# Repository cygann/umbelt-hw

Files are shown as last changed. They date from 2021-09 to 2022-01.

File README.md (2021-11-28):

# umbelt-hw

This repo contains the hardware files for Umbelt: a sensory substitution belt
for everyday use. Designed to be worn around the waist underneath any belt,
Umbelt doesn't compromise on function or style. The name Umbelt (pronounced
"oom-belt") is a pun on the German word umwelt, used in English to describe an
organism's sensory environment and perceptions.

Sensory substitution "is a change of the characteristics of one sensory modality
into stimuli of another sensory modality."
([Wikipedia](https://en.wikipedia.org/wiki/Sensory_substitution))
This means that sensory modalities which are not otherwise accessible to an
individual can be recreated using haptic feedback on the waist. This includes
ordinary sensory functions for prosthetic purposes as well as sensory
information that is beyond typical human senses, such as electromagnetic
radiation outside the visible spectrum, the Earth's magnetic field, time,
physical proximity, velocity, or any other information in the computing world.

The initial configuration to try is the compass feature. This maps one's
absolute orientation to the waist by always indicating where north is whenever
the wearer's orientation changes. After wearing this for a while, the wearer
experiences subtle changes in spatial perception. It becomes more natural to
think in terms of absolute orientation, and separate locations become better
integrated into a larger, more continuous sense of space.

assembled Umbelt image

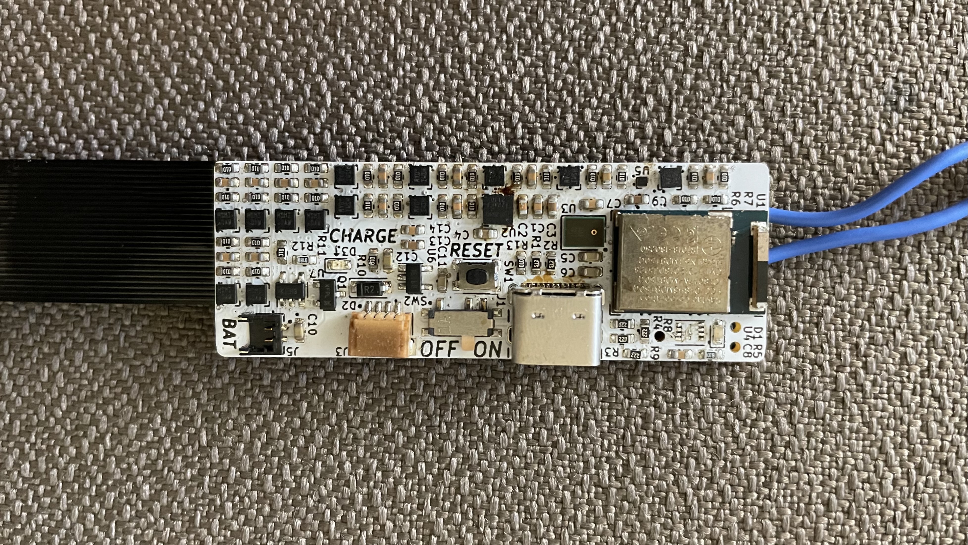
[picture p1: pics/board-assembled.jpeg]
assembled board image


# Hardware Design

Umbelt is designed as an assembly of two printed circuits: a rigid printed
circuit board (PCB) and a flexible printed circuit (FPC). The board mounts all
of the electronic components: the microcontroller, power regulators, 13 motor
drivers, integrated sensors (magnetometer, accelerometer/gyroscope, and
microphone), and connectors. The flex PC connects to the board and wraps around
the wearer's waist, providing electrical connections to 12 of the 13 motors.

The Microcontroller is a Raytac MDBT50Q-1MV2 module based on the Nordic nRF52840
bluetooth microcontroller. This bluetooth connection enables phone-based
configuration of Umbelt. A Sparkfun/Adafruit-style Qwiic expansion connector
allows for the daisy-chaining of additional I2C sensors to Umbelt.

Schematics and layout were designed with KiCad version 5.1.10.

Schematics can be found [here](umbelt-board/umbelt-board.pdf).

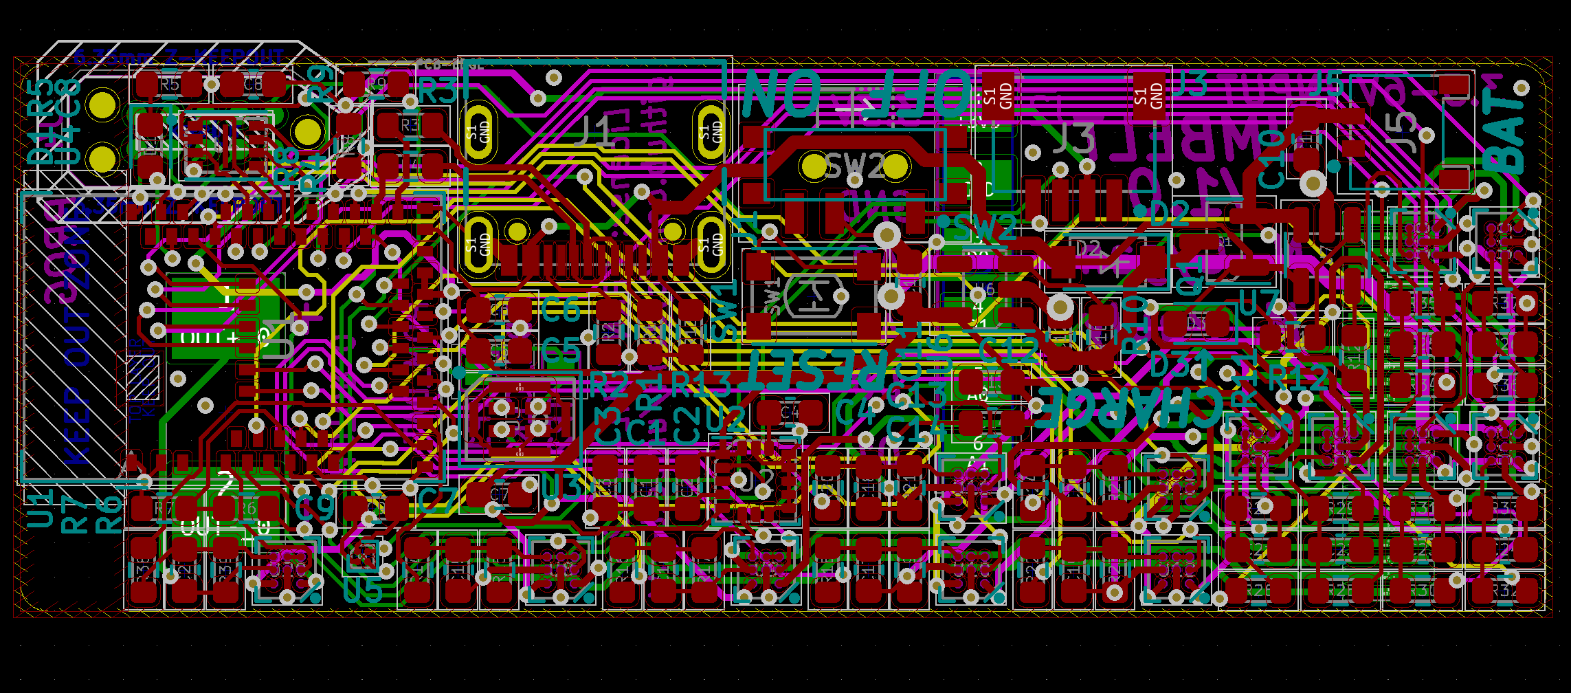
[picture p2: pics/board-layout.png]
board layout image


# Related Repositories

[Software](https://github.com/cygann/umbelt-sw). Haptic effects, sensor
libraries, and user programs.

[Bootloader](https://github.com/cygann/Adafruit_nRF52_Bootloader). This
is a modified version of the Adafruit Feather nRF52840 Sense bootloader, and
that target is to be used when compiling and flashing.

# License

_Creators' note: The aim of this license is to be semi-permissive: Umbelt may
be used in larger projects under different licenses but Umbelt itself and
modifications to it must be open-source under the same license. Refer to license
text for specifics._

Copyright Natalie Cygan and Matthew Pauly 2021.

This source describes Open Hardware and is licensed under the CERN-OHL-W v2 or
later

You may redistribute and modify this documentation and make products
using it under the terms of the CERN-OHL-W v2 (https://ohwr.org/cernohl).
This documentation is distributed WITHOUT ANY EXPRESS OR IMPLIED
WARRANTY, INCLUDING OF MERCHANTABILITY, SATISFACTORY QUALITY
AND FITNESS FOR A PARTICULAR PURPOSE. Please see the CERN-OHL-W v2
for applicable conditions.

Source location: https://github.com/cygann/umbelt-hw

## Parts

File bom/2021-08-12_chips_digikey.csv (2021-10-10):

Index | Quantity | Part Number | Manufacturer Part Number | Description | Customer Reference | Unit Price | Tariff | Extended Price
1 | 5 | 1428-1052-1-ND | ICM-20608-G | IMU ACCEL/GYRO I2C/SPI 16LGA | U2 | 5.97000 | $0.00 | $29.85
2 | 5 | 1267-MMC5633NJLCT-ND | MMC5633NJL | 30 GAUSS, MONOLITHIC, HIGH PERFO | U5 | 1.39200 | $0.70 | $6.96
3 | 5 | 423-1425-1-ND | SPK0641HT4H-1 | RAMIS MIC MULTIMODE DGT TOP PORT | U3 | 1.37000 | $0.69 | $6.85
4 | 5 | 1092-1204-1-ND | MX25R1635FZUIL0 | IC FLASH 16MBIT SPI/QUAD 8USON | U4 | 0.89000 | $0.00 | $4.45
5 | 5 | AP7366-33W5-7DICT-ND | AP7366-33W5-7 | IC REG LINEAR 3.3V 600MA SOT25 | U6 | 0.51000 | $0.26 | $2.55
6 | 5 | MCP73832-2ACI/MC-ND | MCP73832-2ACI/MC | IC BATT CONTRL LI-ION 1CELL 8DFN | U7 | 0.66000 | $0.00 | $3.30
7 | 5 | 785-1193-1-ND | AO3415A | MOSFET P-CH 20V 5A SOT23-3L | Q1 | 0.52000 | $0.26 | $2.60
8 | 5 | MBR0520TPMSCT-ND | MBR0520-TP | DIODE SCHOTTKY 20V 500MA SOD123 | D2 | 0.35000 | $0.18 | $1.75

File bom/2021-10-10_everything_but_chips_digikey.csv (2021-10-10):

Index | Quantity | Part Number | Manufacturer Part Number | Description | Customer Reference | Available | Backorder | Unit Price | Extended Price USD
1 | 5 | 44A0111-28-2-DS-ND | 44A0111-28-2 | 44A0111-28-2 FEET |  | 5 | 0 | 0.65000 | 3.25
2 | 10 | 455-2890-ND | ACHLR-02V-S | CONN RCPT HSG 2POS 1.20MM |  | 10 | 0 | 0.15200 | 1.52
3 | 25 | 455-2914-1-ND | SACHL-003G-P0.2 | CONN FML SKT 28-30AWG CRIMP GOLD |  | 25 | 0 | 0.06440 | 1.61
4 | 1 | 1568-PRT-17258-ND | PRT-17258 | FLEXIBLE QWIIC CABLE - 200MM |  | 1 | 0 | 1.56000 | 1.56
5 | 2 | 1528-4483-ND | 4483 | ARDUINO MKR TO STEMMA QT / QWIIC |  | 2 | 0 | 1.50000 | 3.00
6 | 1 | 1568-PRT-17257-ND | PRT-17257 | FLEXIBLE QWIIC CABLE - 500MM |  | 1 | 0 | 2.19000 | 2.19
7 | 1 | 899-1061-ND | 8.08.91 J-LINK EDU MINI | J-LINK EDU MINI |  | 0 | 1 | 20.35000 | 20.35
8 | 50 | 490-10475-1-ND | GRM188R61A106ME69D | CAP CER 10UF 10V X5R 0603 | C5 C6 C10 C11 C12 | 50 | 0 | 0.07960 | 3.98
9 | 20 | 1276-1183-1-ND | CL10A225KQ8NNNC | CAP CER 2.2UF 6.3V X5R 0603 | C3 C9 C13 | 20 | 0 | 0.04400 | 0.88
10 | 10 | 732-7898-1-ND | 885012106001 | CAP CER 0.47UF 6.3V X5R 0603 | C4 | 10 | 0 | 0.07200 | 0.72
11 | 50 | 478-06036C104KAT4ACT-ND | 06036C104KAT4A | CAP CER 0.1UF 6.3V X7R 0603 | C1 C7 C8 C14 | 50 | 0 | 0.02080 | 1.04
12 | 10 | SML-D12M1WT86CT-ND | SML-D12M1WT86 | LED YLW/GREEN DIFFUSED 1608 SMD | D1 | 10 | 0 | 0.11500 | 1.15
13 | 6 | 2073-USB4105-GF-ACT-ND | USB4105-GF-A | CONN RCP USB2.0 TYP C 24P SMD RA | J1 | 6 | 0 | 0.85000 | 5.10
14 | 6 | 455-1804-1-ND | SM04B-SRSS-TB(LF)(SN) | CONN HEADER SMD R/A 4POS 1MM | J3 | 6 | 0 | 0.55000 | 3.30
15 | 1 | TC2050-IDC-NL-ND | TC2050-IDC-NL | CBL PLUG-OF-NAILS 10-PIN | J4 | 1 | 0 | 39.00000 | 39.00
16 | 6 | 455-2896-1-ND | BM02B-ACHLKS-GAN-ETF(LF)(SN) | CONN HEADER SMD R/A 2POS 1.2MM | J5 | 6 | 0 | 0.59000 | 3.54
17 | 15 | 1292-WR06X1001FTLCT-ND | WR06X1001FTL | RES 1K OHM 1% 1/10W 0603 | R5 R11 | 15 | 0 | 0.01300 | 0.20
18 | 10 | RMCF0603FT10K0CT-ND | RMCF0603FT10K0 | RES 10K OHM 1% 1/10W 0603 | R12 | 10 | 0 | 0.01700 | 0.17
19 | 180 | RMCF0603FT100KCT-ND | RMCF0603FT100K | RES 100K OHM 1% 1/10W 0603 | R6 R7 R10 R13 R14 R15 R16 R17 R18 R19 R20 R21 R2 | 180 | 0 | 0.00680 | 1.22
20 | 15 | RMCF0603FT5K10CT-ND | RMCF0603FT5K10 | RES 5.1K OHM 1% 1/10W 0603 | R1 R2 | 15 | 0 | 0.01700 | 0.26
21 | 15 | 118-CR0603-FX-22R0ELFCT-ND | CR0603-FX-22R0ELF | RES SMD 22 OHM 1% 1/10W 0603 | R3 R4 | 15 | 0 | 0.01700 | 0.26
22 | 15 | RMCF0603FT2K20CT-ND | RMCF0603FT2K20 | RES 2.2K OHM 1% 1/10W 0603 | R8 R9 | 15 | 0 | 0.01700 | 0.26
23 | 6 | CKN10284CT-ND | KMR231NG ULC LFS | SWITCH TACTILE SPST-NO 0.05A 32V | SW1 | 6 | 0 | 0.51000 | 3.06
24 | 6 | 563-1102-1-ND | CUS-12TB | SWITCH SLIDE SPDT 300MA 4V | SW2 | 6 | 0 | 0.70000 | 4.20
25 | 10 | 160-1445-1-ND | LTST-C191KFKT | LED ORANGE CLEAR SMD | D3 | 10 | 0 | 0.13200 | 1.32
26 | 100 | 296-DRV8601NMBRCT-ND | DRV8601NMBR | IC MOTOR DRIVER 2.5V-5.5V 8BGA | U8 U9 U10 U11 U12 U13 U14 U15 U16 U17 U18 U19 U2 | 100 | 0 | 0.69830 | 69.83
27 | 70 | 1670-1090-ND | G1040001D | VIBRATION LRA MOTOR 170HZ 1.5G |  | 70 | 0 | 2.31720 | 162.20
28 | 100 | 1276-2066-1-ND | CL10B472KB8SFNC | CAP CER 4700PF 50V X7R 0603 | C2 C15 C16 C17 C18 C19 C20 C21 C22 C23 C24 C25 C | 100 | 0 | 0.01190 | 1.19

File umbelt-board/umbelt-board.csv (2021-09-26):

Reference | Quantity | Value | Footprint | Datasheet | Comment | Color | Addr
C5 C6 C10 C11 C12 | 5 | 10uF | Capacitor_SMD:C_0603_1608Metric | ~
C2 C15 C16 C17 C18 C19 C20 C21 C22 C23 C24 C25 C26 C27 | 14 | 4.7nF | Capacitor_SMD:C_0603_1608Metric | ~
C3 C9 C13 | 3 | 2.2uF | Capacitor_SMD:C_0603_1608Metric | ~
C4 | 1 | 0.47uF | Capacitor_SMD:C_0603_1608Metric | ~
C1 C7 C8 C14 | 4 | 0.1uF | Capacitor_SMD:C_0603_1608Metric | ~
D1 | 1 | SML-D12M1W | LED_SMD:LED_0603_1608Metric | https://fscdn.rohm.com/en/products/databook/datasheet/opto/led/chip_mono/sml-d12x1-e.pdf |  | Yellow/Green
D2 | 1 | MBR0520 | Diode_SMD:D_SOD-123 | https://www.mccsemi.com/pdf/Products/MBR0520-MBR0580(SOD123).pdf
D3 | 1 | SML-D12D1W | LED_SMD:LED_0603_1608Metric | https://fscdn.rohm.com/en/products/databook/datasheet/opto/led/chip_mono/sml-d12x1-e.pdf |  | Orange
J1 | 1 | USB4105-GF-A | umbelt-board:GCT_USB4105-GF-A | https://gct.co/connector/usb4105
J2 | 1 | Conn_01x06 | umbelt-board:PinHeader_1x06_P2.54mm_Right_Angle_SMD | ~
J3 | 1 | SM04B-SRSS-TB | umbelt-board:JST_SM04B-SRSS-TB(LF)(SN) | https://www.jst-mfg.com/product/pdf/eng/eSH.pdf | Qwiic
J4 | 1 | TC2050-IDC-NL | umbelt-board:Tag-Connect_TC2050-IDC-NL_2x05_P1.27mm_Vertical | https://www.tag-connect.com/wp-content/uploads/bsk-pdf-manager/TC2050-IDC-NL_Datasheet_8.pdf
J5 | 1 | BM02B-ACHLKS | umbelt-board:BM02B-ACHLKS | https://www.jst-mfg.com/product/pdf/eng/eACHL.pdf
J6 | 1 | Conn_Flex_Motor | umbelt-board:Conn_Flex_Motor
J7 | 1 | Conn_Indiv_Motor | umbelt-board:Conn_Indiv_Motor
Q1 | 1 | AO3415A | Package_TO_SOT_SMD:SOT-23 | https://media.digikey.com/pdf/Data%20Sheets/Alpha%20&%20Omega/AO3415A.pdf
R5 R11 | 2 | 1k | Resistor_SMD:R_0603_1608Metric | ~
R12 | 1 | 10k | Resistor_SMD:R_0603_1608Metric | ~
R6 R7 R10 R13 R14 R15 R16 R17 R18 R19 R20 R21 R22 R23 R24 R25 R26 R27 R28 R29 R30 R31 R32 R33 R34 R35 R36 R37 R38 R39 | 30 | 100k | Resistor_SMD:R_0603_1608Metric | ~
R1 R2 | 2 | 5.1k | Resistor_SMD:R_0603_1608Metric | ~
R3 R4 | 2 | 22 | Resistor_SMD:R_0603_1608Metric | ~
R8 R9 | 2 | 2.2k | Resistor_SMD:R_0603_1608Metric | ~
SW1 | 1 | KMR231NG-ULC-LFS | umbelt-board:KMR2-NG | https://www.ckswitches.com/media/1479/kmr2.pdf
SW2 | 1 | CUS-12TB | umbelt-board:CUS-12B | https://www.nidec-copal-electronics.com/e/catalog/switch/cus.pdf
TP1 | 1 | PDM_DAT | TestPoint:TestPoint_Pad_1.0x1.0mm | ~
TP2 | 1 | PDM_CLK | TestPoint:TestPoint_Pad_1.0x1.0mm | ~
U1 | 1 | MDBT50Q-1MV2 | umbelt-board:Raytac_MDBT50Q | https://www.raytac.com/download/index.php?index_id=43
U2 | 1 | ICM-20608 | Package_LGA:LGA-16_3x3mm_P0.5mm_LayoutBorder3x5y | https://invensense.tdk.com/wp-content/uploads/2015/03/DS-000081-v1.01.pdf |  |  | addr=7'h68
U3 | 1 | SPK0641HT4H-1 | umbelt-board:Knowles_SPK0641HT4H-1 | https://www.knowles.com/docs/default-source/model-downloads/spk0641ht4h-1-rev-a.pdf
U4 | 1 | MX25R1635FZUIL0 | umbelt-board:USON-8_2x3 | https://www.macronix.com/Lists/Datasheet/Attachments/7595/MX25R1635F%2c%20Wide%20Range%2c%2016Mb%2c%20v1.6.pdf
U5 | 1 | MMC5633NJL | umbelt-board:WLP-4_0.86x0.86mm_P0.4mm | https://media.digikey.com/pdf/Data%20Sheets/MEMSIC%20PDFs/MMC5633NJL_RevA_3-12-20.pdf |  |  | Addr=7'h30
U6 | 1 | AP7366-33W5 | Package_TO_SOT_SMD:SOT-23-5 | https://www.diodes.com/assets/Datasheets/AP7366.pdf
U7 | 1 | MCP73832-2ACI_MC‎ | Package_TO_SOT_SMD:SOT-23-5 | http://ww1.microchip.com/downloads/en/DeviceDoc/20001984g.pdf
U8 U9 U10 U11 U12 U13 U14 U15 U16 U17 U18 U19 U20 | 13 | DRV8601 | umbelt-board:BGA-8_3x3_2.1x2.1mm_TI_ZQV | https://www.ti.com/lit/ds/symlink/drv8601.pdf

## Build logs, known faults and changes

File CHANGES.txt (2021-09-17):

This file contains a summary of modifications that a licensee makes to this
design. Information about the design should be added but never removed from
this file. For more details see the license text or the license user guide.

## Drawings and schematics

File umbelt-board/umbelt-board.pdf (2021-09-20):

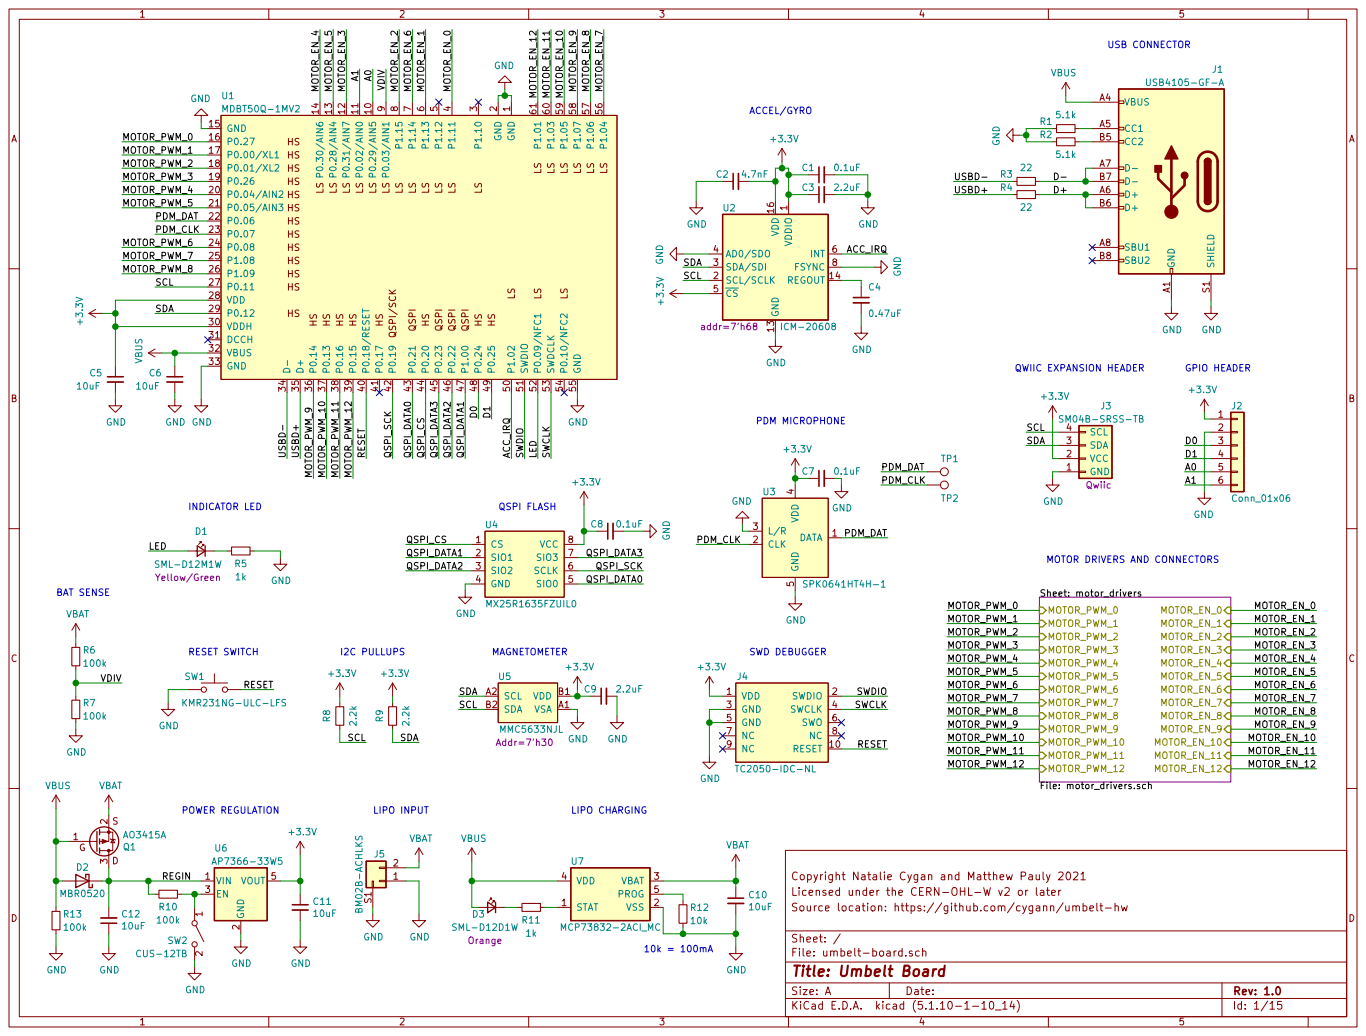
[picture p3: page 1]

9 U1MDBT50Q-1MV2 GND GND GND GND VBUS ACC_IRQ

3 VDDH 30 DCCH 31 VBUS 32 GND 33 D- 34 D+ 35 P0.14 36 P0.13 37 P0.16 38 P0.15 39 P1.11

1 2 SW2 CUS-12TB +3.3V HSHSHSHSHSHSHSHSHSHSHSHSHS HSHSHSHSHSHSHSHS LSLSLSLSLSLSLSLSLSLSLSLS LSLS LSLS LS LSLSLSLS QSPI QSPI QSPI QSPI QSPI/SCK GND

1 GND 13 REGOUT 14 VDD 16 SCL/SCLK 2 SDA/SDI 3 AD0/SDO 4 CS 5

J3 SM04B-SRSS-TB Qwiic D1 SML-D12M1W
PDM MICROPHONE RESET SWITCH
GND

File: umbelt-board.sch Sheet: / Source location: https://github.com/cygann/umbelt-hw

Id: 1/15 Title: Umbelt Board

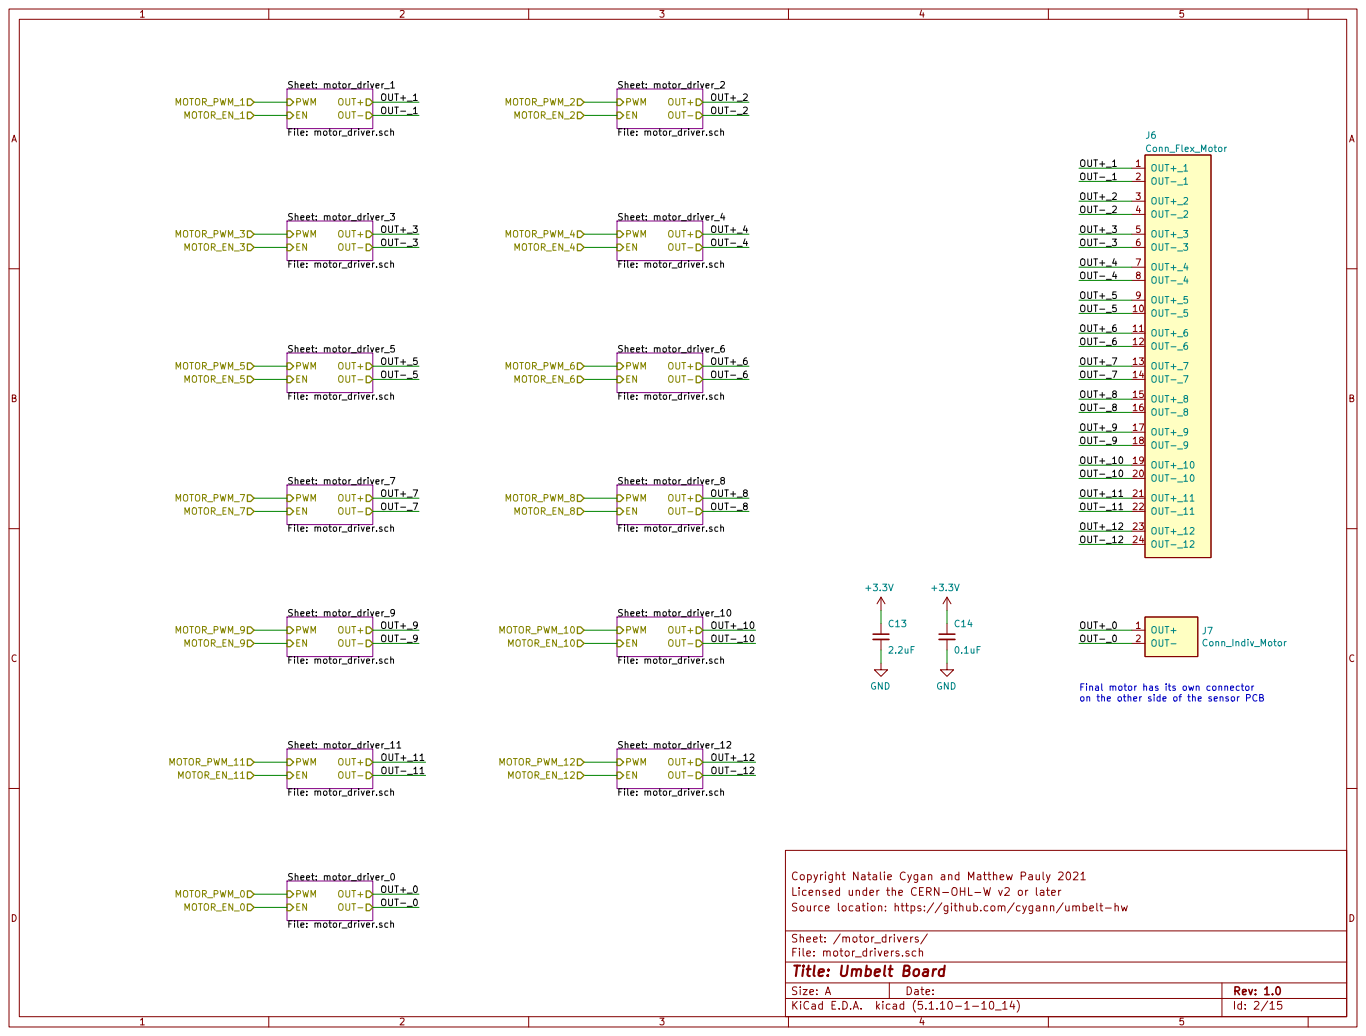
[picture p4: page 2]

Sheet: motor_driver_1 File: motor_driver.sch PWM

Sheet: motor_driver_2 File: motor_driver.sch PWM

Sheet: motor_driver_0 File: motor_driver.sch PWM

Licensed under the CERN-OHL-W v2 or later Copyright Natalie Cygan and Matthew Pauly 2021

Source location: https://github.com/cygann/umbelt-hw
Sheet: /motor_drivers/
File: motor_drivers.sch
Id: 2/15 Title: Umbelt Board

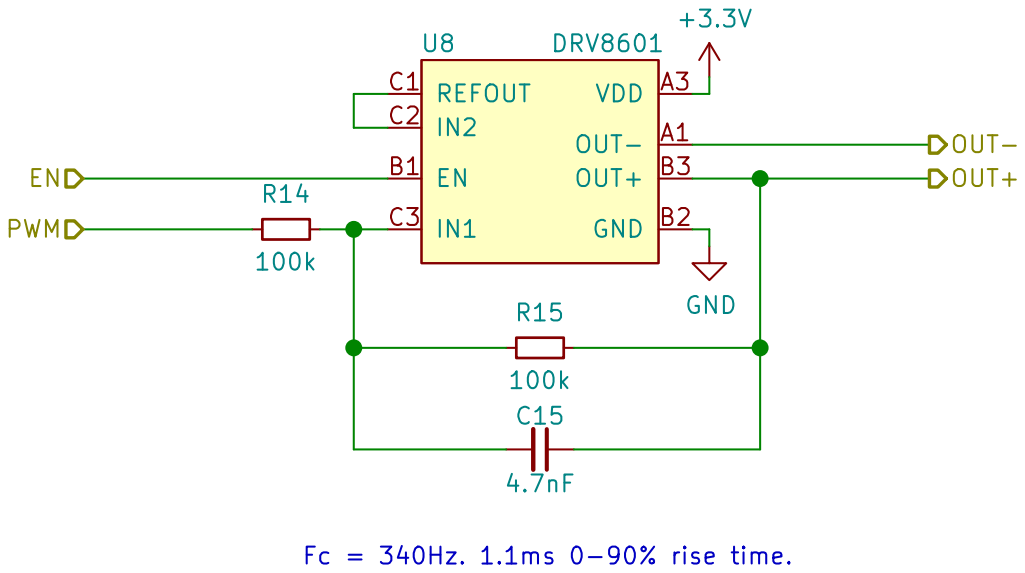
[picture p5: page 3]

Licensed under the CERN-OHL-W v2 or later Copyright Natalie Cygan and Matthew Pauly 2021

Source location: https://github.com/cygann/umbelt-hw
Sheet: /motor_drivers/motor_driver_1/
File: motor_driver.sch
Id: 3/15 Title: Umbelt Board

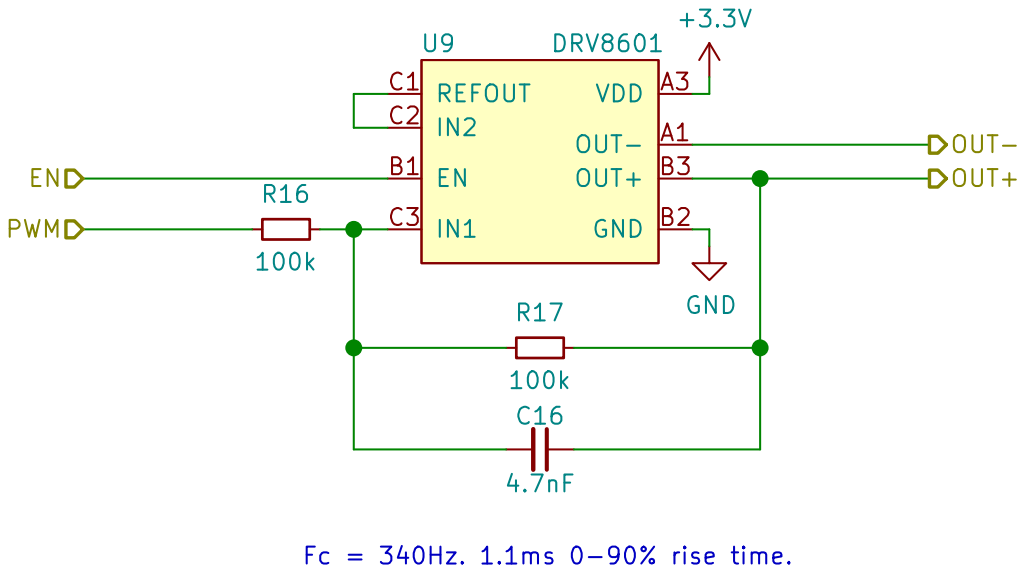
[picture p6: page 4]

Licensed under the CERN-OHL-W v2 or later Copyright Natalie Cygan and Matthew Pauly 2021

Source location: https://github.com/cygann/umbelt-hw
Sheet: /motor_drivers/motor_driver_2/
File: motor_driver.sch
Id: 4/15 Title: Umbelt Board

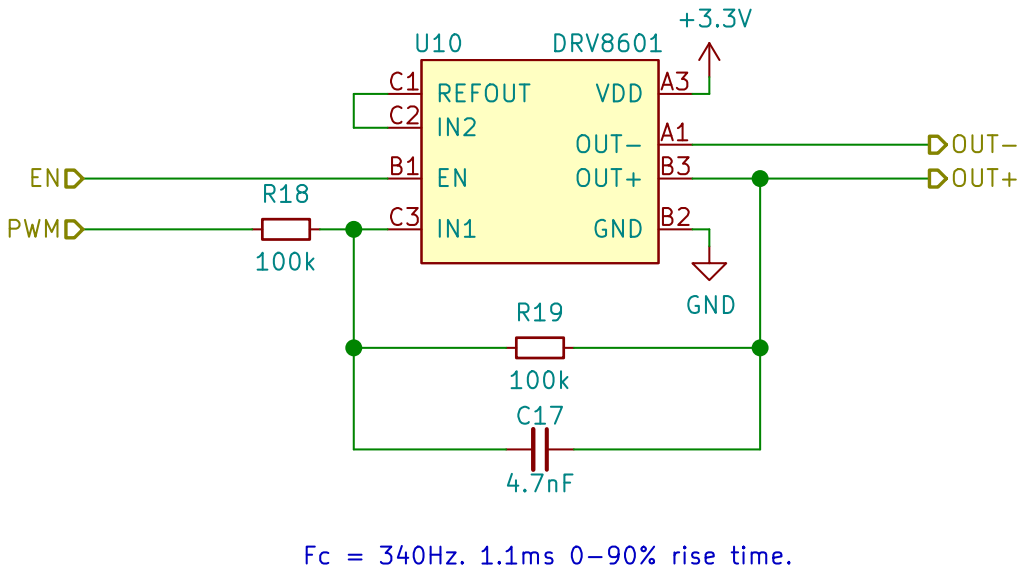
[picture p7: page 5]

Licensed under the CERN-OHL-W v2 or later Copyright Natalie Cygan and Matthew Pauly 2021

Source location: https://github.com/cygann/umbelt-hw
Sheet: /motor_drivers/motor_driver_3/
File: motor_driver.sch
Id: 5/15 Title: Umbelt Board

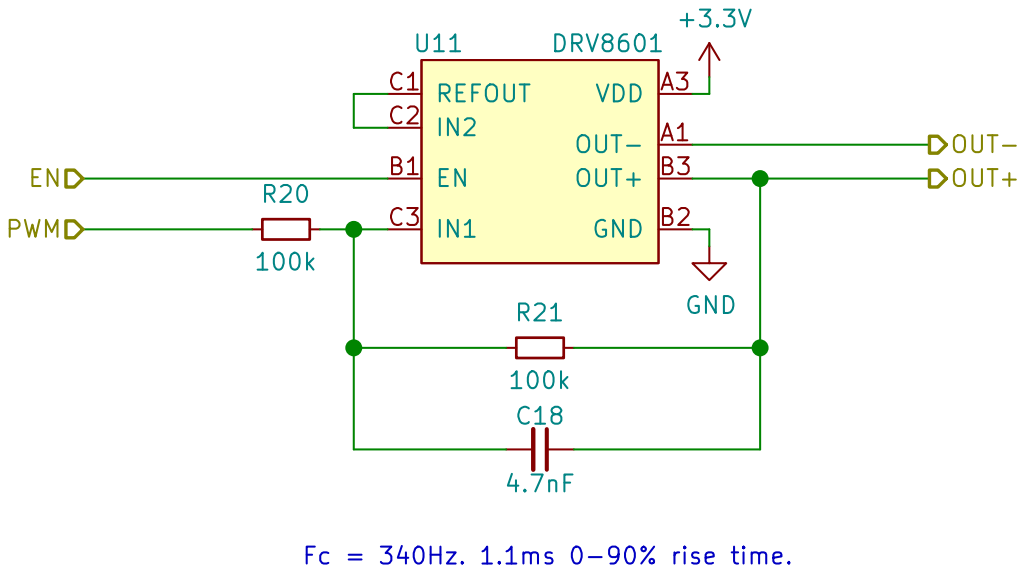
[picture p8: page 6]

Licensed under the CERN-OHL-W v2 or later Copyright Natalie Cygan and Matthew Pauly 2021

Source location: https://github.com/cygann/umbelt-hw
Sheet: /motor_drivers/motor_driver_4/
File: motor_driver.sch
Id: 6/15 Title: Umbelt Board

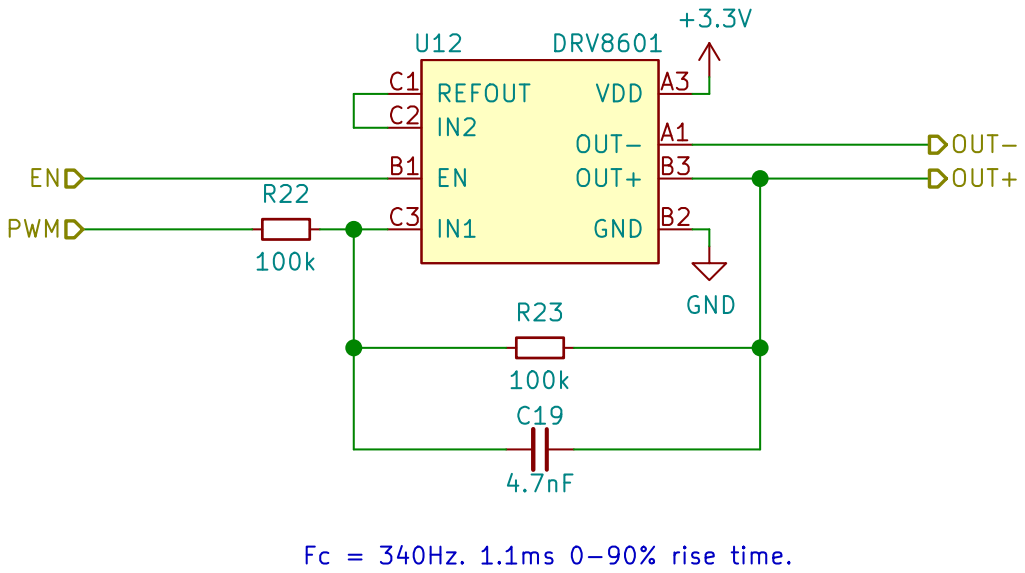
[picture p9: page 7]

Licensed under the CERN-OHL-W v2 or later Copyright Natalie Cygan and Matthew Pauly 2021

Source location: https://github.com/cygann/umbelt-hw
Sheet: /motor_drivers/motor_driver_5/
File: motor_driver.sch
Id: 7/15 Title: Umbelt Board

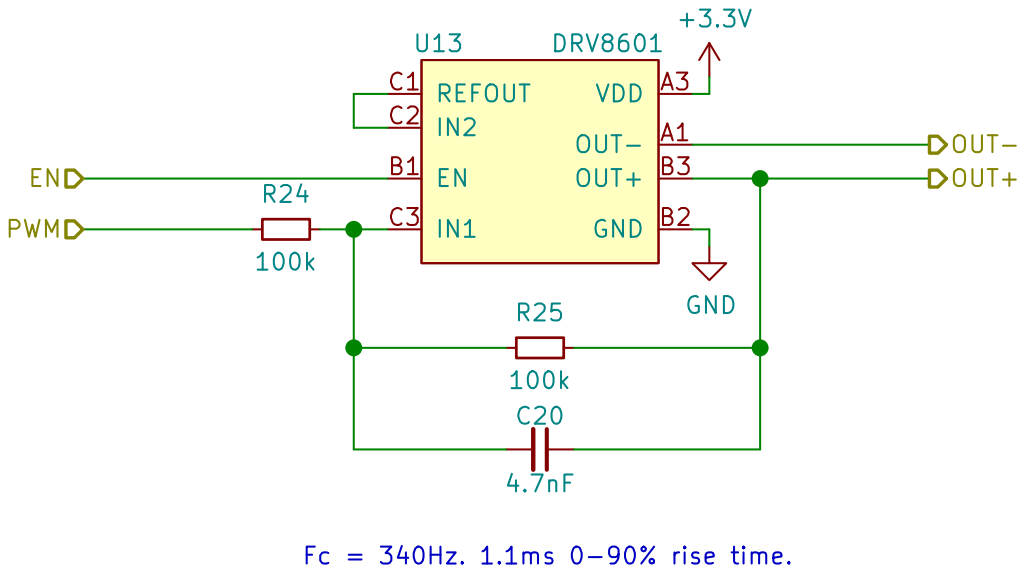
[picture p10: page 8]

Licensed under the CERN-OHL-W v2 or later Copyright Natalie Cygan and Matthew Pauly 2021

Source location: https://github.com/cygann/umbelt-hw
Sheet: /motor_drivers/motor_driver_6/
File: motor_driver.sch
Id: 8/15 Title: Umbelt Board

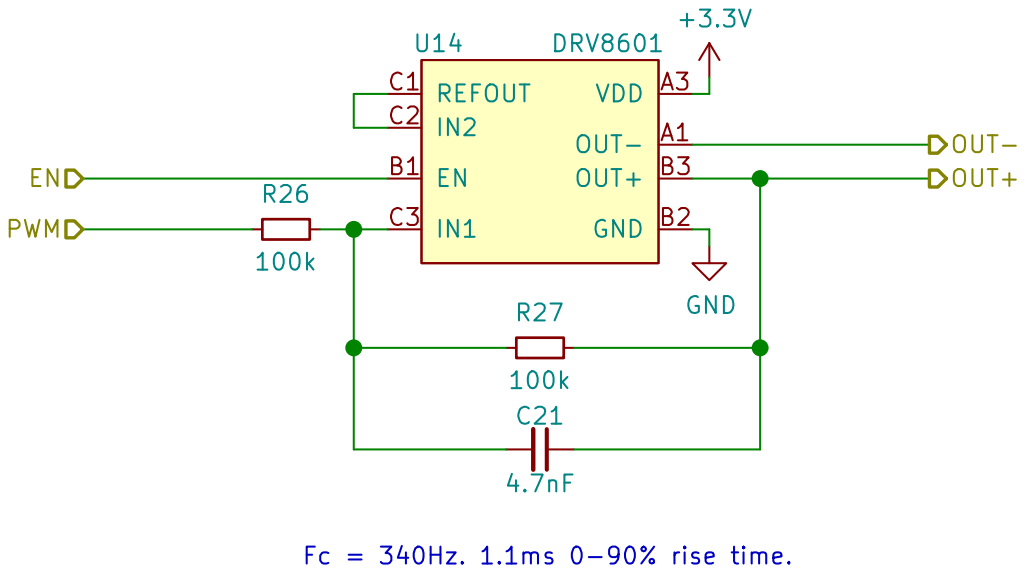
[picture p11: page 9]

Licensed under the CERN-OHL-W v2 or later Copyright Natalie Cygan and Matthew Pauly 2021

Source location: https://github.com/cygann/umbelt-hw
Sheet: /motor_drivers/motor_driver_7/
File: motor_driver.sch
Id: 9/15 Title: Umbelt Board

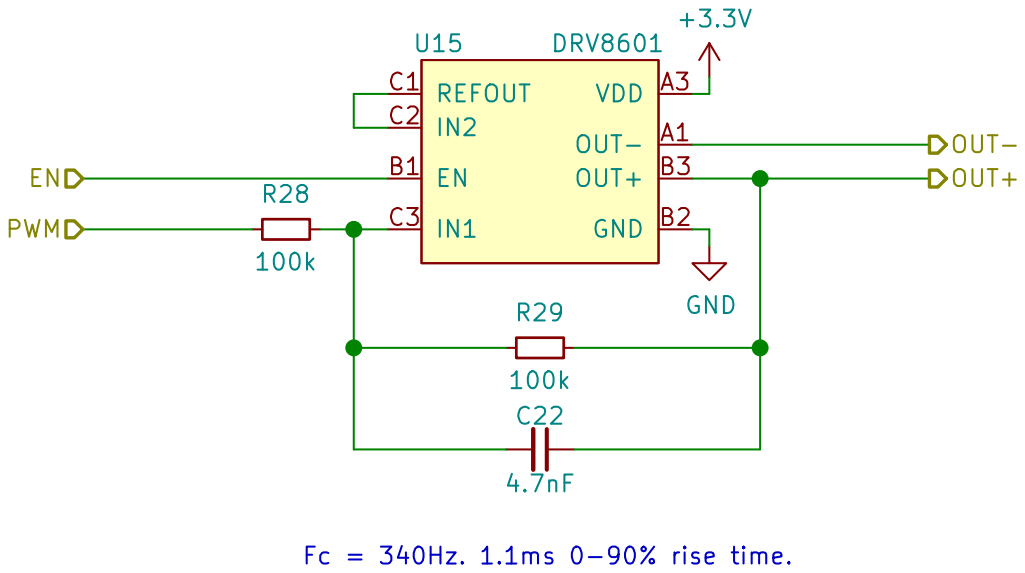
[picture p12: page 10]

Licensed under the CERN-OHL-W v2 or later Copyright Natalie Cygan and Matthew Pauly 2021

Source location: https://github.com/cygann/umbelt-hw
Sheet: /motor_drivers/motor_driver_8/
File: motor_driver.sch
Id: 10/15 Title: Umbelt Board

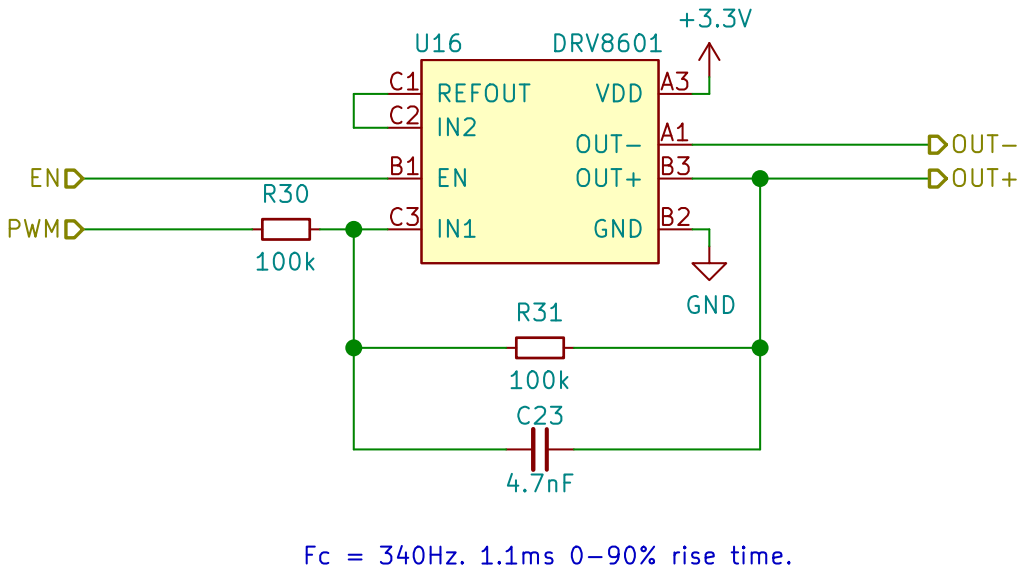
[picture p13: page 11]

Licensed under the CERN-OHL-W v2 or later Copyright Natalie Cygan and Matthew Pauly 2021

Source location: https://github.com/cygann/umbelt-hw
Sheet: /motor_drivers/motor_driver_9/
File: motor_driver.sch
Id: 11/15 Title: Umbelt Board

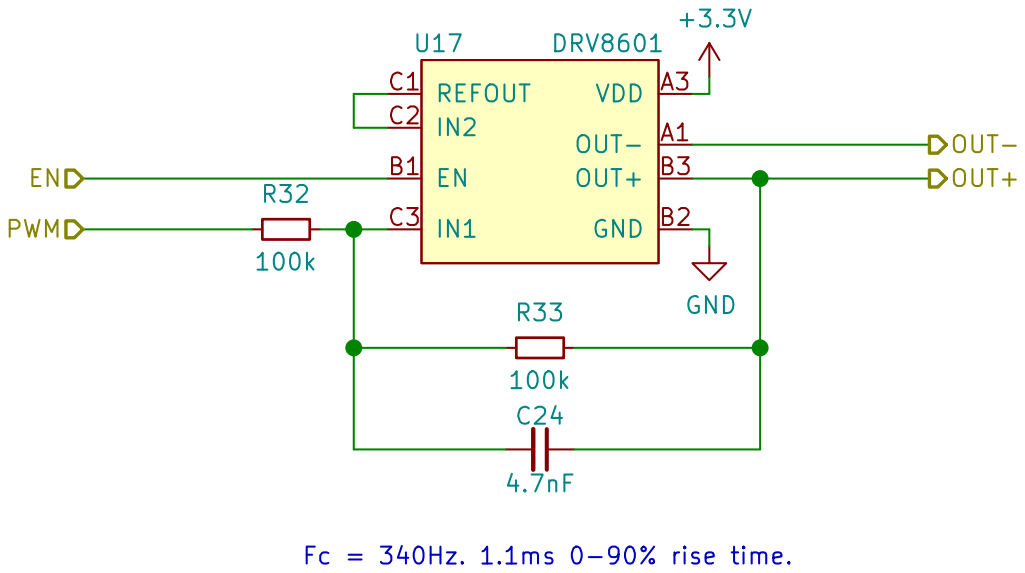
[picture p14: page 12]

Licensed under the CERN-OHL-W v2 or later Copyright Natalie Cygan and Matthew Pauly 2021

Source location: https://github.com/cygann/umbelt-hw
Sheet: /motor_drivers/motor_driver_10/
File: motor_driver.sch
Id: 12/15 Title: Umbelt Board


Licensed under the CERN-OHL-W v2 or later Copyright Natalie Cygan and Matthew Pauly 2021

Source location: https://github.com/cygann/umbelt-hw
Sheet: /motor_drivers/motor_driver_11/
File: motor_driver.sch
Id: 13/15 Title: Umbelt Board


Licensed under the CERN-OHL-W v2 or later Copyright Natalie Cygan and Matthew Pauly 2021

Source location: https://github.com/cygann/umbelt-hw
Sheet: /motor_drivers/motor_driver_12/
File: motor_driver.sch
Id: 14/15 Title: Umbelt Board


Licensed under the CERN-OHL-W v2 or later Copyright Natalie Cygan and Matthew Pauly 2021

Source location: https://github.com/cygann/umbelt-hw
Sheet: /motor_drivers/motor_driver_0/
File: motor_driver.sch
Id: 15/15 Title: Umbelt Board

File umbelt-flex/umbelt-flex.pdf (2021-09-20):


Licensed under the CERN-OHL-W v2 or later Copyright Natalie Cygan and Matthew Pauly 2021

File: umbelt-flex.sch Sheet: / Source location: https://github.com/cygann/umbelt-hw

Id: 1/1 Title: Umbelt Flex

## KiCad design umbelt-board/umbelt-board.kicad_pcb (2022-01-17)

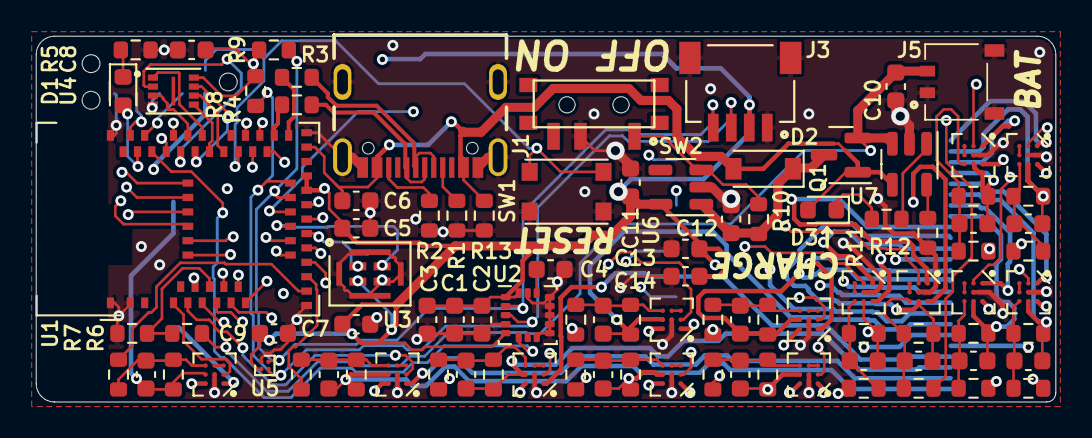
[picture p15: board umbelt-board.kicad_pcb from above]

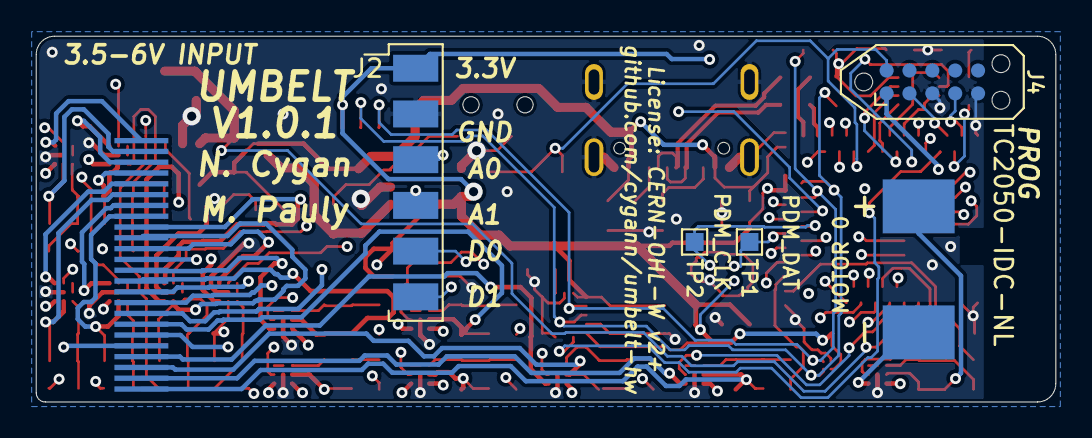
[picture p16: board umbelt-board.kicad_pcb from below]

Board: 4 copper layers, 56.6 x 20.3 mm, 101 parts (6 on the bottom side), 115 nets.

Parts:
C1, C7, C8, C14: 0.1uF; C_0603_1608Metric
C2, C15, C16, C17, C18, C19, C20, C21, C22, C23, C24, C25, C26, C27: 4.7nF; C_0603_1608Metric
C3, C9, C13: 2.2uF; C_0603_1608Metric
C4: 0.47uF; C_0603_1608Metric
C5, C6, C10, C11, C12: 10uF; C_0603_1608Metric
D1: SML-D12M1W; LED_0603_1608Metric
D2: MBR0520; D_SOD-123
D3: SML-D12D1W; LED_0603_1608Metric
J1: USB4105-GF-A; GCT_USB4105-GF-A
J2: Conn_01x06; PinHeader_1x06_P2.54mm_Right_Angle_SMD
J3: SM04B-SRSS-TB; JST_SM04B-SRSS-TB(LF)(SN)
J4: TC2050-IDC-NL; Tag-Connect_TC2050-IDC-NL_2x05_P1.27mm_Vertical
J5: BM02B-ACHLKS
J6: Conn_Flex_Motor
J7: Conn_Indiv_Motor
Q1: AO3415A; SOT-23
R1, R2: 5.1k; R_0603_1608Metric
R3, R4: 22; R_0603_1608Metric
R5, R11: 1k; R_0603_1608Metric
R6, R7, R10, R13, R14, R15, R16, R17, R18, R19, R20, R21, R22, R23, R24, R25, R26, R27, R28, R29, R30, R31, R32, R33, R34, R35, R36, R37, R38, R39: 100k; R_0603_1608Metric
R8, R9: 2.2k; R_0603_1608Metric
R12: 10k; R_0603_1608Metric
SW1: KMR231NG-ULC-LFS; KMR2-NG
SW2: CUS-12TB; CUS-12B
TP1: PDM_DAT; TestPoint_Pad_1.0x1.0mm
TP2: PDM_CLK; TestPoint_Pad_1.0x1.0mm
U1: MDBT50Q-1MV2; Raytac_MDBT50Q
U2: ICM-20608; LGA-16_3x3mm_P0.5mm_LayoutBorder3x5y
U3: SPK0641HT4H-1; Knowles_SPK0641HT4H-1
U4: MX25R1635FZUIL0; USON-8_2x3
U5: MMC5633NJL; WLP-4_0.86x0.86mm_P0.4mm
U6: AP7366-33W5; SOT-23-5
U7: MCP73832-2ACI_MC‎; SOT-23-5
U8, U9, U10, U11, U12, U13, U14, U15, U16, U17, U18, U19, U20: DRV8601; BGA-8_3x3_2.1x2.1mm_TI_ZQV

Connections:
+3V3: C1.1, C2.2, C3.1, C5.1, C7.1, C8.1, C9.1, C11.1, C13.1, C14.1, J2.1, J3.2, J4.1, R8.1, R9.1, U1.28, U1.30, U2.1, U2.5, U2.16, U3.4, U4.8, U5.B1, U6.5, U8.A3, U9.A3, U10.A3, U11.A3, U12.A3, U13.A3, U14.A3, U15.A3, U16.A3, U17.A3, U18.A3, U19.A3, U20.A3
/A0: J2.5, U1.10
/A1: J2.6, U1.11
/ACC_IRQ: U1.50, U2.6
/D0: J2.3, U1.48
/D1: J2.4, U1.49
/D+: J1.A6, J1.B6, R4.1
/D-: J1.A7, J1.B7, R3.1
/LED: D1.2, U1.52
/MOTOR_EN_0: U1.4, U20.B1
/MOTOR_EN_1: U1.6, U8.B1
/MOTOR_EN_2: U1.8, U9.B1
/MOTOR_EN_3: U1.12, U10.B1
/MOTOR_EN_4: U1.14, U11.B1
/MOTOR_EN_5: U1.13, U12.B1
/MOTOR_EN_6: U1.7, U13.B1
/MOTOR_EN_7: U1.56, U14.B1
/MOTOR_EN_8: U1.57, U15.B1
/MOTOR_EN_9: U1.58, U16.B1
/MOTOR_EN_10: U1.59, U17.B1
/MOTOR_EN_11: U1.60, U18.B1
/MOTOR_EN_12: U1.61, U19.B1
/MOTOR_PWM_0: R38.1, U1.16
/MOTOR_PWM_1: R14.1, U1.17
/MOTOR_PWM_2: R16.1, U1.18
/MOTOR_PWM_3: R18.1, U1.19
/MOTOR_PWM_4: R20.1, U1.20
/MOTOR_PWM_5: R22.1, U1.21
/MOTOR_PWM_6: R24.1, U1.24
/MOTOR_PWM_7: R26.1, U1.25
/MOTOR_PWM_8: R28.1, U1.26
/MOTOR_PWM_9: R30.1, U1.36
/MOTOR_PWM_10: R32.1, U1.37
/MOTOR_PWM_11: R34.1, U1.38
/MOTOR_PWM_12: R36.1, U1.39
/PDM_CLK: TP2.1, U1.23, U3.2
/PDM_DAT: TP1.1, U1.22, U3.1
/QSPI_CS: U1.44, U4.1
/QSPI_DATA0: U1.43, U4.5
/QSPI_DATA1: U1.47, U4.2
/QSPI_DATA2: U1.46, U4.3
/QSPI_DATA3: U1.45, U4.7
/QSPI_SCK: U1.42, U4.6
/REGIN: C12.2, D2.1, Q1.3, R10.1, U6.1
/RESET: J4.10, SW1.2, U1.40
/SCL: J3.4, R9.2, U1.27, U2.2, U5.A2
/SDA: J3.3, R8.2, U1.29, U2.3, U5.B2
/SWCLK: J4.4, U1.53
/SWDIO: J4.2, U1.51
/USBD+: R4.2, U1.35
/USBD-: R3.2, U1.34
/VDIV: R6.2, R7.1, U1.9
/motor_drivers/OUT+_0: C27.1, J7.1, R39.2, U20.B3
/motor_drivers/OUT+_1: C15.1, J6.1, R15.2, U8.B3
/motor_drivers/OUT+_2: C16.1, J6.3, R17.2, U9.B3
/motor_drivers/OUT+_3: C17.1, J6.5, R19.2, U10.B3
/motor_drivers/OUT+_4: C18.1, J6.7, R21.2, U11.B3
/motor_drivers/OUT+_5: C19.1, J6.9, R23.2, U12.B3
/motor_drivers/OUT+_6: C20.1, J6.11, R25.2, U13.B3
/motor_drivers/OUT+_7: C21.1, J6.13, R27.2, U14.B3
/motor_drivers/OUT+_8: C22.1, J6.15, R29.2, U15.B3
/motor_drivers/OUT+_9: C23.1, J6.17, R31.2, U16.B3
/motor_drivers/OUT+_10: C24.1, J6.19, R33.2, U17.B3
/motor_drivers/OUT+_11: C25.1, J6.21, R35.2, U18.B3
/motor_drivers/OUT+_12: C26.1, J6.23, R37.2, U19.B3
/motor_drivers/OUT-_0: J7.2, U20.A1
/motor_drivers/OUT-_1: J6.2, U8.A1
/motor_drivers/OUT-_2: J6.4, U9.A1
/motor_drivers/OUT-_3: J6.6, U10.A1
/motor_drivers/OUT-_4: J6.8, U11.A1
/motor_drivers/OUT-_5: J6.10, U12.A1
/motor_drivers/OUT-_6: J6.12, U13.A1
/motor_drivers/OUT-_7: J6.14, U14.A1
/motor_drivers/OUT-_8: J6.16, U15.A1
/motor_drivers/OUT-_9: J6.18, U16.A1
/motor_drivers/OUT-_10: J6.20, U17.A1
/motor_drivers/OUT-_11: J6.22, U18.A1
/motor_drivers/OUT-_12: J6.24, U19.A1
GND: C1.2, C2.1, C3.2, C4.2, C5.2, C6.2, C7.2, C8.2, C9.2, C10.2, C11.2, C12.1, C13.2, C14.2, J1.A1, J1.A12, J1.B1, J1.B12, J1.S1, J2.2, J3.1, J3.S1, J4.3, J4.5, J5.1, J5.S1, R1.2, R2.2, R5.2, R7.2, R12.2, R13.2, SW1.1, SW2.2, U1.1, U1.2, U1.15, U1.33, U1.55, U2.4, U2.8, U2.9, U2.10, U2.11, U2.12, U2.13, U2.15, U3.3, U3.5, U3.6, U3.7, U3.8, U4.4, U5.A1, U6.2, U7.2, U8.B2, U9.B2, U10.B2, U11.B2, U12.B2, U13.B2, U14.B2, U15.B2, U16.B2, U17.B2, U18.B2, U19.B2, U20.B2
unnamed: C4.1, U2.14
unnamed: C15.2, R14.2, R15.1, U8.C3
unnamed: C16.2, R16.2, R17.1, U9.C3
unnamed: C17.2, R18.2, R19.1, U10.C3
unnamed: C18.2, R20.2, R21.1, U11.C3
unnamed: C19.2, R22.2, R23.1, U12.C3
unnamed: C20.2, R24.2, R25.1, U13.C3
unnamed: C21.2, R26.2, R27.1, U14.C3
unnamed: C22.2, R28.2, R29.1, U15.C3
unnamed: C23.2, R30.2, R31.1, U16.C3
unnamed: C24.2, R32.2, R33.1, U17.C3
unnamed: C25.2, R34.2, R35.1, U18.C3
unnamed: C26.2, R36.2, R37.1, U19.C3
unnamed: C27.2, R38.2, R39.1, U20.C3
unnamed: D1.1, R5.1
unnamed: D3.1, R11.1
unnamed: J1.A5, R1.1
unnamed: J1.B5, R2.1
unnamed: R10.2, SW2.1, U6.3
unnamed: R11.2, U7.1
unnamed: R12.1, U7.5
unnamed: U8.C1, U8.C2
unnamed: U9.C1, U9.C2
unnamed: U10.C1, U10.C2
unnamed: U11.C1, U11.C2
unnamed: U12.C1, U12.C2
unnamed: U13.C1, U13.C2
unnamed: U14.C1, U14.C2
unnamed: U15.C1, U15.C2
unnamed: U16.C1, U16.C2
unnamed: U17.C1, U17.C2
unnamed: U18.C1, U18.C2
unnamed: U19.C1, U19.C2
unnamed: U20.C1, U20.C2
VBAT: C10.1, J5.2, Q1.2, R6.1, U7.3
VBUS: C6.1, D2.2, D3.2, J1.A4, J1.A9, J1.B4, J1.B9, Q1.1, R13.1, U1.32, U7.4

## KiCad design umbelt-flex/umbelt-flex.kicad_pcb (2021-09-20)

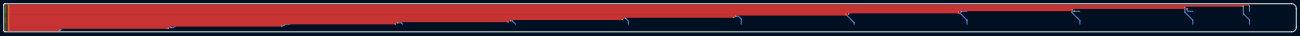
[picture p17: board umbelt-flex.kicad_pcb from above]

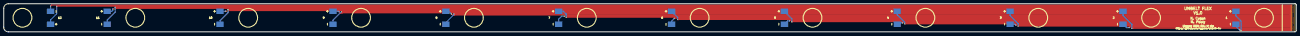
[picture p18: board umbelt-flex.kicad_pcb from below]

Board: 2 copper layers, 701.0 x 15.2 mm, 13 parts (12 on the bottom side), 24 nets.

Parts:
J1, J2, J3, J4, J5, J6, J7, J8, J9, J10, J11, J12: Conn_Indiv_Motor
J13: Conn_Flex_Motor

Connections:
/OUT+_1: J1.1, J13.1
/OUT+_2: J2.1, J13.3
/OUT+_3: J3.1, J13.5
/OUT+_4: J4.1, J13.7
/OUT+_5: J5.1, J13.9
/OUT+_6: J6.1, J13.11
/OUT+_7: J7.1, J13.13
/OUT+_8: J8.1, J13.15
/OUT+_9: J9.1, J13.17
/OUT+_10: J10.1, J13.19
/OUT+_11: J11.1, J13.21
/OUT+_12: J12.1, J13.23
/OUT-_1: J1.2, J13.2
/OUT-_2: J2.2, J13.4
/OUT-_3: J3.2, J13.6
/OUT-_4: J4.2, J13.8
/OUT-_5: J5.2, J13.10
/OUT-_6: J6.2, J13.12
/OUT-_7: J7.2, J13.14
/OUT-_8: J8.2, J13.16
/OUT-_9: J9.2, J13.18
/OUT-_10: J10.2, J13.20
/OUT-_11: J11.2, J13.22
/OUT-_12: J12.2, J13.24

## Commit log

2021-07-26 Initial kicad project
    [umbelt-board.kicad_pcb, umbelt-board.sch]
2021-08-04 add project local schematic lib, add motor buffers, update gitignore
    [umbelt-board.sch]
2021-08-10 add nRF module, SWD connector, flex PCB connector, qwiic connector
    [umbelt-board.sch]
2021-08-12 add usb connector, gpio header, pdm microphone, i2c pullups
    [umbelt-board.sch]
2021-08-19 add motor driver schematic sheet, footprints for most parts, motion sensor schematic components
    [motor_drivers.sch, umbelt-board.sch]
2021-08-24 complete schematics and footprints
    [motor_driver.sch, motor_drivers.sch, umbelt-board.sch]
2021-08-24 pass electrical rules check, annotate schematics, assign all footprints, generate netlist
    [motor_driver.sch, motor_drivers.sch, umbelt-board.sch]
2021-08-24 add BOM
    [umbelt-board.csv]
2021-08-24 Initial commit for umbelt flex pcb
    [umbelt-flex.kicad_pcb, umbelt-flex.sch]
2021-08-24 start layout, tweak some footprints
    [motor_drivers.sch, umbelt-board.csv, umbelt-board.kicad_pcb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]
2021-08-24 Umbelt flex schematics
    [umbelt-flex.sch]
2021-08-25 more placement, update custom footprints' ref des on fab layer
    [umbelt-board.kicad_pcb]
2021-08-27 add SMD pin header, finished placement
    [motor_driver.sch, umbelt-board.kicad_pcb, umbelt-board.sch]
2021-09-08 tweak placement, add text, add test points, add rounded corners
    [motor_driver.sch, umbelt-board.kicad_pcb, umbelt-board.sch]
2021-09-10 lots of routing; hard part done
    [umbelt-board.kicad_pcb, umbelt-board.sch]
2021-09-17 more routing
    [umbelt-board.kicad_pcb, umbelt-board.sch]
2021-09-17 Add license
    [motor_driver.sch, motor_drivers.sch, umbelt-board.kicad_pcb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]
2021-09-17 add source location to sch and pcb
    [motor_driver.sch, motor_drivers.sch, umbelt-board.kicad_pcb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]
2021-09-18 complete routing. passes important DRC checks
    [umbelt-board.kicad_pcb]
2021-09-18 tweak ground pours
    [umbelt-board.kicad_pcb]
2021-09-20 complete flex pcb, generate gerbers for both boards
    [umbelt-board-B_Cu.gbl, umbelt-board-B_Mask.gbs, umbelt-board-B_Paste.gbp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]
2021-09-26 add exported BOM
    [umbelt-board.csv]
2021-10-10 add priced BOM
    [2021-08-12_chips_digikey.csv, 2021-10-10_everything_but_chips_digikey.csv]
2022-01-17 fix SCL/SDA swap on magnetometer, generate outputs
    [motor_driver.sch, motor_drivers.sch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]

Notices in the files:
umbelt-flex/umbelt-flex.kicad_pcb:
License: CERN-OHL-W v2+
